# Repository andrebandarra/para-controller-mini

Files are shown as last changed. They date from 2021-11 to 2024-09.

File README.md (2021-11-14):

<h1 align="center">Para Controller Mini</h1>

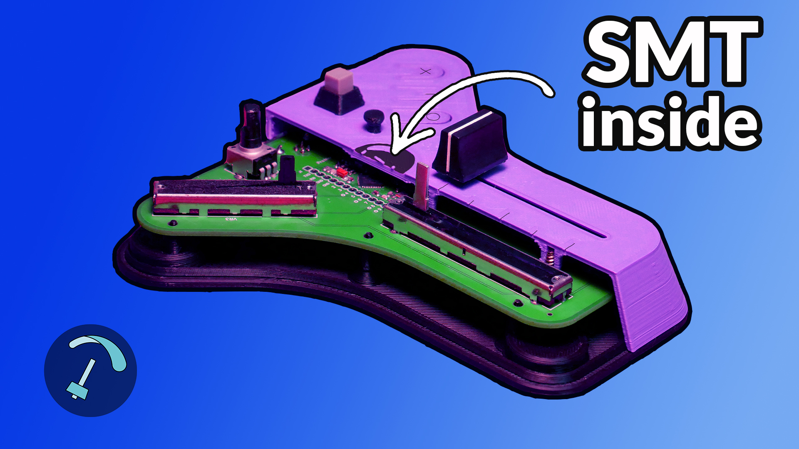
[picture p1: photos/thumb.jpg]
Table


https://www.youtube.com/watch?v=AOkSkCXVu8w --- https://andrebandarra.com/store/pcmini

## Description
I needed a small project to learn about SMT PCB design so this small game controller was the perfect project. I had to create my own Arduino Pro Micro with Surface mount components and was really happy that everything worked first time!

It is based on the Arduino Pro Micro by Sparkfun. I modified the original Eagle files to make a bigger board with space for all the SMT components and then ordered the half-done boards from JLCPCB. 

Then in-house I soldered the THT components like potentiometers, buttons, etc, and burned an arduino bootloader into the fresh 32U4 chips. Then thy can be programmed by the Arduino IDE.

Also created custom cases and 3D printed them. Finished plug and play units are available on my website.

## Features
* Plug and play game controller 
* Based on the Arduino Pro Micro (pins available for expansion and modification)
* Uses Joystick library, acts as a windows/mac default game controller
* 2 big linear potentiometers
* 1 small linear potentiometer
* 1 rotary potentiometer
* 1 latching switch
* 3 temporary switches
* 1 reset switch
* Usb interface

[andrebandarra.com](https://andrebandarra.com/) --- [Youtube](https://www.youtube.com/channel/UCzYf1cmKwDMSiII9SSp6IJw) --- [Patreon](https://www.patreon.com/bandarra)

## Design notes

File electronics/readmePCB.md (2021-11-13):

editable pcb files on EasyEDA

https://easyeda.com/Bandarra/test-import

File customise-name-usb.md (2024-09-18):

<h2>How to customise the USB name of your Arduino based Joystick</h2>
To customize the name of your Arduino-based joystick so that it's recognized with a custom name by Unity (or any operating system), you need to modify the USB descriptors on the Arduino. Since you are using an Arduino Micro, which is based on the ATmega32U4, it has native USB capabilities, and you can adjust the name via its firmware.

* In the Arduino IDE, go to the installation folder and find the boards.txt file:
C:\Program Files (x86)\Arduino\hardware\arduino\avr

* Open your text editor in Admin mode.

* Change the usb_product line to the name you want your device to show up as. It will look something like this:
micro.build.usb_product="ParaController Mini"

* Reflash the Arduino

Keep in mind that if the Arduino IDE or core libraries are updated, your changes might get overwritten, so you may want to back up these changes or use a custom boards file.

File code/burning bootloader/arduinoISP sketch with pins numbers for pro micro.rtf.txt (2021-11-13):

// ArduinoISP
// Copyright (c) 2008-2011 Randall Bohn
// If you require a license, see
// http://www.opensource.org/licenses/bsd-license.php
//
// This sketch turns the Arduino into a AVRISP using the following Arduino pins:
//
// Pin 10 is used to reset the target microcontroller.
//
// By default, the hardware SPI pins MISO, MOSI and SCK are used to communicate
// with the target. On all Arduinos, these pins can be found
// on the ICSP/SPI header:
//
//               MISO °. . 5V (!) Avoid this pin on Due, Zero...
//               SCK   . . MOSI
//                     . . GND
//
// On some Arduinos (Uno,...), pins MOSI, MISO and SCK are the same pins as
// digital pin 11, 12 and 13, respectively. That is why many tutorials instruct
// you to hook up the target to these pins. If you find this wiring more
// practical, have a define USE_OLD_STYLE_WIRING. This will work even when not
// using an Uno. (On an Uno this is not needed).
//
// Alternatively you can use any other digital pin by configuring
// software ('BitBanged') SPI and having appropriate defines for PIN_MOSI,
// PIN_MISO and PIN_SCK.
//
// IMPORTANT: When using an Arduino that is not 5V tolerant (Due, Zero, ...) as
// the programmer, make sure to not expose any of the programmer's pins to 5V.
// A simple way to accomplish this is to power the complete system (programmer
// and target) at 3V3.
//
// Put an LED (with resistor) on the following pins:
// 9: Heartbeat   - shows the programmer is running
// 8: Error       - Lights up if something goes wrong (use red if that makes sense)
// 7: Programming - In communication with the slave
//

#include "Arduino.h"
#undef SERIAL

#define PROG_FLICKER true

// Configure SPI clock (in Hz).
// E.g. for an ATtiny @ 128 kHz: the datasheet states that both the high and low
// SPI clock pulse must be > 2 CPU cycles, so take 3 cycles i.e. divide target
// f_cpu by 6:
//     #define SPI_CLOCK            (128000/6)
//
// A clock slow enough for an ATtiny85 @ 1 MHz, is a reasonable default:

#define SPI_CLOCK                 (1000000/6)

// Select hardware or software SPI, depending on SPI clock.
// Currently only for AVR, for other architectures (Due, Zero,...), hardware SPI
// is probably too fast anyway.

#if defined(ARDUINO_ARCH_AVR)

#if SPI_CLOCK > (F_CPU / 128)
#define USE_HARDWARE_SPI
#endif

#endif

// Configure which pins to use:

// The standard pin configuration.
#ifndef ARDUINO_HOODLOADER2

#define RESET     19 // Use pin 19 to reset the target rather than SS
#define LED_HB    9
#define LED_ERR   8
#define LED_PMODE 7

// Uncomment following line to use the old Uno style wiring
// (using pin 11, 12 and 13 instead of the SPI header) on Leonardo, Due...

// #define USE_OLD_STYLE_WIRING

#ifdef USE_OLD_STYLE_WIRING

#define PIN_MOSI        16
#define PIN_MISO        14
#define PIN_SCK                15

#endif

// HOODLOADER2 means running sketches on the ATmega16U2 serial converter chips
// on Uno or Mega boards. We must use pins that are broken out:
#else

#define RESET             4
#define LED_HB            7
#define LED_ERR           6
#define LED_PMODE         5

#endif

// By default, use hardware SPI pins:
#ifndef PIN_MOSI
#define PIN_MOSI         MOSI
#endif

#ifndef PIN_MISO
#define PIN_MISO         MISO
#endif

#ifndef PIN_SCK
#define PIN_SCK         SCK
#endif

// Force bitbanged SPI if not using the hardware SPI pins:
#if (PIN_MISO != MISO) ||  (PIN_MOSI != MOSI) || (PIN_SCK != SCK)
#undef USE_HARDWARE_SPI
#endif

// Configure the serial port to use.
//
// Prefer the USB virtual serial port (aka. native USB port), if the Arduino has one:
//   - it does not autoreset (except for the magic baud rate of 1200).
//   - it is more reliable because of USB handshaking.
//
// Leonardo and similar have an USB virtual serial port: 'Serial'.
// Due and Zero have an USB virtual serial port: 'SerialUSB'.
//
// On the Due and Zero, 'Serial' can be used too, provided you disable autoreset.
// To use 'Serial': #define SERIAL Serial

#ifdef SERIAL_PORT_USBVIRTUAL
#define SERIAL SERIAL_PORT_USBVIRTUAL
#else
#define SERIAL Serial
#endif

// Configure the baud rate:

#define BAUDRATE        19200
// #define BAUDRATE        115200
// #define BAUDRATE        1000000

#define HWVER 2
#define SWMAJ 1
#define SWMIN 18

// STK Definitions
#define STK_OK      0x10
#define STK_FAILED  0x11
#define STK_UNKNOWN 0x12
#define STK_INSYNC  0x14
#define STK_NOSYNC  0x15
#define CRC_EOP     0x20 //ok it is a space...

void pulse(int pin, int times);

#ifdef USE_HARDWARE_SPI
#include "SPI.h"
#else

#define SPI_MODE0 0x00

class SPISettings {
  public:
    // clock is in Hz
    SPISettings(uint32_t clock, uint8_t bitOrder, uint8_t dataMode) : clock(clock) {
      (void) bitOrder;
      (void) dataMode;
    };

  private:
    uint32_t clock;

    friend class BitBangedSPI;
};

class BitBangedSPI {
  public:
    void begin() {
      digitalWrite(PIN_SCK, LOW);
      digitalWrite(PIN_MOSI, LOW);
      pinMode(PIN_SCK, OUTPUT);
      pinMode(PIN_MOSI, OUTPUT);
      pinMode(PIN_MISO, INPUT);
    }

    void beginTransaction(SPISettings settings) {
      pulseWidth = (500000 + settings.clock - 1) / settings.clock;
      if (pulseWidth == 0)
        pulseWidth = 1;
    }

    void end() {}

    uint8_t transfer (uint8_t b) {
      for (unsigned int i = 0; i < 8; ++i) {
        digitalWrite(PIN_MOSI, (b & 0x80) ? HIGH : LOW);
        digitalWrite(PIN_SCK, HIGH);
        delayMicroseconds(pulseWidth);
        b = (b << 1) | digitalRead(PIN_MISO);
        digitalWrite(PIN_SCK, LOW); // slow pulse
        delayMicroseconds(pulseWidth);
      }
      return b;
    }

  private:
    unsigned long pulseWidth; // in microseconds
};

static BitBangedSPI SPI;

#endif

void setup() {
  SERIAL.begin(BAUDRATE);

  pinMode(LED_PMODE, OUTPUT);
  pulse(LED_PMODE, 2);
  pinMode(LED_ERR, OUTPUT);
  pulse(LED_ERR, 2);
  pinMode(LED_HB, OUTPUT);
  pulse(LED_HB, 2);

}

int error = 0;
int pmode = 0;
// address for reading and writing, set by 'U' command
unsigned int here;
uint8_t buff[256]; // global block storage

#define beget16(addr) (*addr * 256 + *(addr+1) )
typedef struct param {
  uint8_t devicecode;
  uint8_t revision;
  uint8_t progtype;
  uint8_t parmode;
  uint8_t polling;
  uint8_t selftimed;
  uint8_t lockbytes;
  uint8_t fusebytes;
  uint8_t flashpoll;
  uint16_t eeprompoll;
  uint16_t pagesize;
  uint16_t eepromsize;
  uint32_t flashsize;
}
parameter;

parameter param;

// this provides a heartbeat on pin 9, so you can tell the software is running.
uint8_t hbval = 128;
int8_t hbdelta = 8;
void heartbeat() {
  static unsigned long last_time = 0;
  unsigned long now = millis();
  if ((now - last_time) < 40)
    return;
  last_time = now;
  if (hbval > 192) hbdelta = -hbdelta;
  if (hbval < 32) hbdelta = -hbdelta;
  hbval += hbdelta;
  analogWrite(LED_HB, hbval);
}

static bool rst_active_high;

void reset_target(bool reset) {
  digitalWrite(RESET, ((reset && rst_active_high) || (!reset && !rst_active_high)) ? HIGH : LOW);
}

void loop(void) {
  // is pmode active?
  if (pmode) {
    digitalWrite(LED_PMODE, HIGH);
  } else {
    digitalWrite(LED_PMODE, LOW);
  }
  // is there an error?
  if (error) {
    digitalWrite(LED_ERR, HIGH);
  } else {
    digitalWrite(LED_ERR, LOW);
  }

  // light the heartbeat LED
  heartbeat();
  if (SERIAL.available()) {
    avrisp();
  }
}

uint8_t getch() {
  while (!SERIAL.available());
  return SERIAL.read();
}
void fill(int n) {
  for (int x = 0; x < n; x++) {
    buff[x] = getch();
  }
}

#define PTIME 30
void pulse(int pin, int times) {
  do {
    digitalWrite(pin, HIGH);
    delay(PTIME);
    digitalWrite(pin, LOW);
    delay(PTIME);
  } while (times--);
}

void prog_lamp(int state) {
  if (PROG_FLICKER) {
    digitalWrite(LED_PMODE, state);
  }
}

uint8_t spi_transaction(uint8_t a, uint8_t b, uint8_t c, uint8_t d) {
  SPI.transfer(a);
  SPI.transfer(b);
  SPI.transfer(c);
  return SPI.transfer(d);
}

void empty_reply() {
  if (CRC_EOP == getch()) {
    SERIAL.print((char)STK_INSYNC);
    SERIAL.print((char)STK_OK);
  } else {
    error++;
    SERIAL.print((char)STK_NOSYNC);
  }
}

void breply(uint8_t b) {
  if (CRC_EOP == getch()) {
    SERIAL.print((char)STK_INSYNC);
    SERIAL.print((char)b);
    SERIAL.print((char)STK_OK);
  } else {
    error++;
    SERIAL.print((char)STK_NOSYNC);
  }
}

void get_version(uint8_t c) {
  switch (c) {
    case 0x80:
      breply(HWVER);
      break;
    case 0x81:
      breply(SWMAJ);
      break;
    case 0x82:
      breply(SWMIN);
      break;
    case 0x93:
      breply('S'); // serial programmer
      break;
    default:
      breply(0);
  }
}

void set_parameters() {
  // call this after reading parameter packet into buff[]
  param.devicecode = buff[0];
  param.revision   = buff[1];
  param.progtype   = buff[2];
  param.parmode    = buff[3];
  param.polling    = buff[4];
  param.selftimed  = buff[5];
  param.lockbytes  = buff[6];
  param.fusebytes  = buff[7];
  param.flashpoll  = buff[8];
  // ignore buff[9] (= buff[8])
  // following are 16 bits (big endian)
  param.eeprompoll = beget16(&buff[10]);
  param.pagesize   = beget16(&buff[12]);
  param.eepromsize = beget16(&buff[14]);

  // 32 bits flashsize (big endian)
  param.flashsize = buff[16] * 0x01000000
                    + buff[17] * 0x00010000
                    + buff[18] * 0x00000100
                    + buff[19];

  // AVR devices have active low reset, AT89Sx are active high
  rst_active_high = (param.devicecode >= 0xe0);
}

void start_pmode() {

  // Reset target before driving PIN_SCK or PIN_MOSI

  // SPI.begin() will configure SS as output, so SPI master mode is selected.
  // We have defined RESET as pin 10, which for many Arduinos is not the SS pin.
  // So we have to configure RESET as output here,
  // (reset_target() first sets the correct level)
  reset_target(true);
  pinMode(RESET, OUTPUT);
  SPI.begin();
  SPI.beginTransaction(SPISettings(SPI_CLOCK, MSBFIRST, SPI_MODE0));

  // See AVR datasheets, chapter "SERIAL_PRG Programming Algorithm":

  // Pulse RESET after PIN_SCK is low:
  digitalWrite(PIN_SCK, LOW);
  delay(20); // discharge PIN_SCK, value arbitrarily chosen
  reset_target(false);
  // Pulse must be minimum 2 target CPU clock cycles so 100 usec is ok for CPU
  // speeds above 20 KHz
  delayMicroseconds(100);
  reset_target(true);

  // Send the enable programming command:
  delay(50); // datasheet: must be > 20 msec
  spi_transaction(0xAC, 0x53, 0x00, 0x00);
  pmode = 1;
}

void end_pmode() {
  SPI.end();
  // We're about to take the target out of reset so configure SPI pins as input
  pinMode(PIN_MOSI, INPUT);
  pinMode(PIN_SCK, INPUT);
  reset_target(false);
  pinMode(RESET, INPUT);
  pmode = 0;
}

void universal() {
  uint8_t ch;

  fill(4);
  ch = spi_transaction(buff[0], buff[1], buff[2], buff[3]);
  breply(ch);
}

void flash(uint8_t hilo, unsigned int addr, uint8_t data) {
  spi_transaction(0x40 + 8 * hilo,
                  addr >> 8 & 0xFF,
                  addr & 0xFF,
                  data);
}
void commit(unsigned int addr) {
  if (PROG_FLICKER) {
    prog_lamp(LOW);
  }
  spi_transaction(0x4C, (addr >> 8) & 0xFF, addr & 0xFF, 0);
  if (PROG_FLICKER) {
    delay(PTIME);
    prog_lamp(HIGH);
  }
}

unsigned int current_page() {
  if (param.pagesize == 32) {
    return here & 0xFFFFFFF0;
  }
  if (param.pagesize == 64) {
    return here & 0xFFFFFFE0;
  }
  if (param.pagesize == 128) {
    return here & 0xFFFFFFC0;
  }
  if (param.pagesize == 256) {
    return here & 0xFFFFFF80;
  }
  return here;
}

void write_flash(int length) {
  fill(length);
  if (CRC_EOP == getch()) {
    SERIAL.print((char) STK_INSYNC);
    SERIAL.print((char) write_flash_pages(length));
  } else {
    error++;
    SERIAL.print((char) STK_NOSYNC);
  }
}

uint8_t write_flash_pages(int length) {
  int x = 0;
  unsigned int page = current_page();
  while (x < length) {
    if (page != current_page()) {
      commit(page);
      page = current_page();
    }
    flash(LOW, here, buff[x++]);
    flash(HIGH, here, buff[x++]);
    here++;
  }

  commit(page);

  return STK_OK;
}

#define EECHUNK (32)
uint8_t write_eeprom(unsigned int length) {
  // here is a word address, get the byte address
  unsigned int start = here * 2;
  unsigned int remaining = length;
  if (length > param.eepromsize) {
    error++;
    return STK_FAILED;
  }
  while (remaining > EECHUNK) {
    write_eeprom_chunk(start, EECHUNK);
    start += EECHUNK;
    remaining -= EECHUNK;
  }
  write_eeprom_chunk(start, remaining);
  return STK_OK;
}
// write (length) bytes, (start) is a byte address
uint8_t write_eeprom_chunk(unsigned int start, unsigned int length) {
  // this writes byte-by-byte, page writing may be faster (4 bytes at a time)
  fill(length);
  prog_lamp(LOW);
  for (unsigned int x = 0; x < length; x++) {
    unsigned int addr = start + x;
    spi_transaction(0xC0, (addr >> 8) & 0xFF, addr & 0xFF, buff[x]);
    delay(45);
  }
  prog_lamp(HIGH);
  return STK_OK;
}

void program_page() {
  char result = (char) STK_FAILED;
  unsigned int length = 256 * getch();
  length += getch();
  char memtype = getch();
  // flash memory @here, (length) bytes
  if (memtype == 'F') {
    write_flash(length);
    return;
  }
  if (memtype == 'E') {
    result = (char)write_eeprom(length);
    if (CRC_EOP == getch()) {
      SERIAL.print((char) STK_INSYNC);
      SERIAL.print(result);
    } else {
      error++;
      SERIAL.print((char) STK_NOSYNC);
    }
    return;
  }
  SERIAL.print((char)STK_FAILED);
  return;
}

uint8_t flash_read(uint8_t hilo, unsigned int addr) {
  return spi_transaction(0x20 + hilo * 8,
                         (addr >> 8) & 0xFF,
                         addr & 0xFF,
                         0);
}

char flash_read_page(int length) {
  for (int x = 0; x < length; x += 2) {
    uint8_t low = flash_read(LOW, here);
    SERIAL.print((char) low);
    uint8_t high = flash_read(HIGH, here);
    SERIAL.print((char) high);
    here++;
  }
  return STK_OK;
}

char eeprom_read_page(int length) {
  // here again we have a word address
  int start = here * 2;
  for (int x = 0; x < length; x++) {
    int addr = start + x;
    uint8_t ee = spi_transaction(0xA0, (addr >> 8) & 0xFF, addr & 0xFF, 0xFF);
    SERIAL.print((char) ee);
  }
  return STK_OK;
}

void read_page() {
  char result = (char)STK_FAILED;
  int length = 256 * getch();
  length += getch();
  char memtype = getch();
  if (CRC_EOP != getch()) {
    error++;
    SERIAL.print((char) STK_NOSYNC);
    return;
  }
  SERIAL.print((char) STK_INSYNC);
  if (memtype == 'F') result = flash_read_page(length);
  if (memtype == 'E') result = eeprom_read_page(length);
  SERIAL.print(result);
}

void read_signature() {
  if (CRC_EOP != getch()) {
    error++;
    SERIAL.print((char) STK_NOSYNC);
    return;
  }
  SERIAL.print((char) STK_INSYNC);
  uint8_t high = spi_transaction(0x30, 0x00, 0x00, 0x00);
  SERIAL.print((char) high);
  uint8_t middle = spi_transaction(0x30, 0x00, 0x01, 0x00);
  SERIAL.print((char) middle);
  uint8_t low = spi_transaction(0x30, 0x00, 0x02, 0x00);
  SERIAL.print((char) low);
  SERIAL.print((char) STK_OK);
}
//////////////////////////////////////////
//////////////////////////////////////////

////////////////////////////////////
////////////////////////////////////
void avrisp() {
  uint8_t ch = getch();
  switch (ch) {
    case '0': // signon
      error = 0;
      empty_reply();
      break;
    case '1':
      if (getch() == CRC_EOP) {
        SERIAL.print((char) STK_INSYNC);
        SERIAL.print("AVR ISP");
        SERIAL.print((char) STK_OK);
      }
      else {
        error++;
        SERIAL.print((char) STK_NOSYNC);
      }
      break;
    case 'A':
      get_version(getch());
      break;
    case 'B':
      fill(20);
      set_parameters();
      empty_reply();
      break;
    case 'E': // extended parameters - ignore for now
      fill(5);
      empty_reply();
      break;
    case 'P':
      if (!pmode)
        start_pmode();
      empty_reply();
      break;
    case 'U': // set address (word)
      here = getch();
      here += 256 * getch();
      empty_reply();
      break;

    case 0x60: //STK_PROG_FLASH
      getch(); // low addr
      getch(); // high addr
      empty_reply();
      break;
    case 0x61: //STK_PROG_DATA
      getch(); // data
      empty_reply();
      break;

    case 0x64: //STK_PROG_PAGE
      program_page();
      break;

    case 0x74: //STK_READ_PAGE 't'
      read_page();
      break;

    case 'V': //0x56
      universal();
      break;
    case 'Q': //0x51
      error = 0;
      end_pmode();
      empty_reply();
      break;

    case 0x75: //STK_READ_SIGN 'u'
      read_signature();
      break;

    // expecting a command, not CRC_EOP
    // this is how we can get back in sync
    case CRC_EOP:
      error++;
      SERIAL.print((char) STK_NOSYNC);
      break;

    // anything else we will return STK_UNKNOWN
    default:
      error++;
      if (CRC_EOP == getch())
        SERIAL.print((char)STK_UNKNOWN);
      else
        SERIAL.print((char)STK_NOSYNC);
  }
}

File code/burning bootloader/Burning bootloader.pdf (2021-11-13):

Burning arduino bootloader to 32U4 chip using another arduino pro micro

--- Skip Step 0 and Step 1 if already have master arduino and cable ready ---

Step 0
Connect master arduino pro micro to computer via usb
Step 1
Using Arduino IDE upload modified ArduinoISP sketch (in this folder) to the master arduino pro micro
(modification is Pin reset >19, PIN_MOSI > 16, PIN_MISO > 14, PIN_SCK > 15)
Step 2
Connect Master pro micro to Slave pro micro via ISP pins + GND&VCC + pin19 (master to Reset (slave)
- When using Master/slave custom cable, make sure VCC and GND match on both boards
Step 3
Select Tools > Programmer: > Arduino as ISP (ATmega32U4)
Step 4
Click Tools > Burn Bootloader
Step 5
Takes about 5-10 seconds, when done all 3 LEDs on slave arduino micro come on. Unplug usb cable and all ready to go

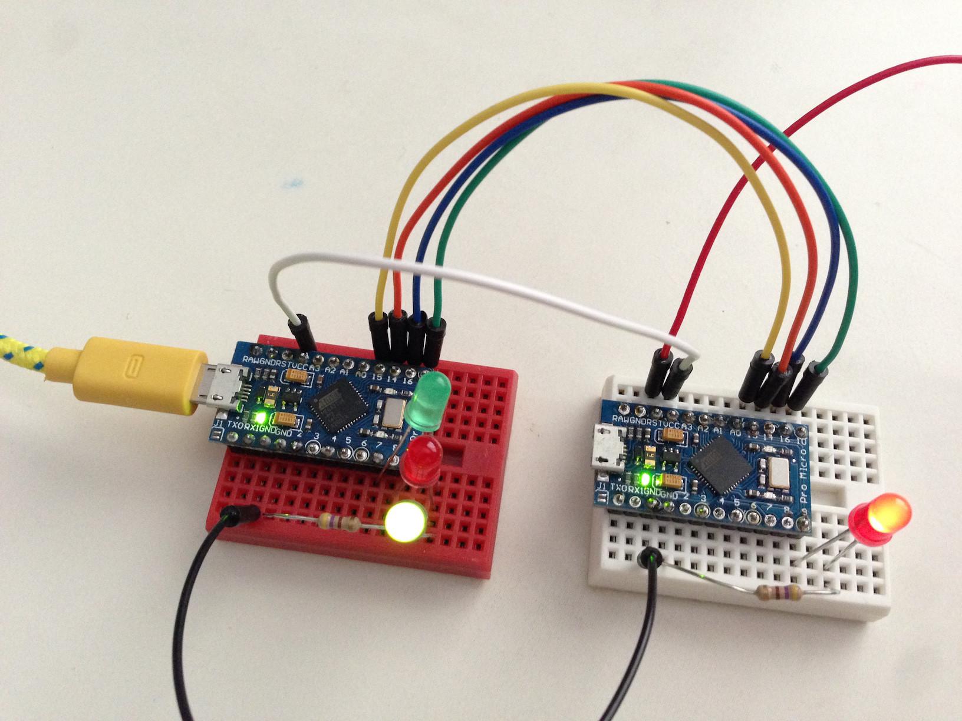
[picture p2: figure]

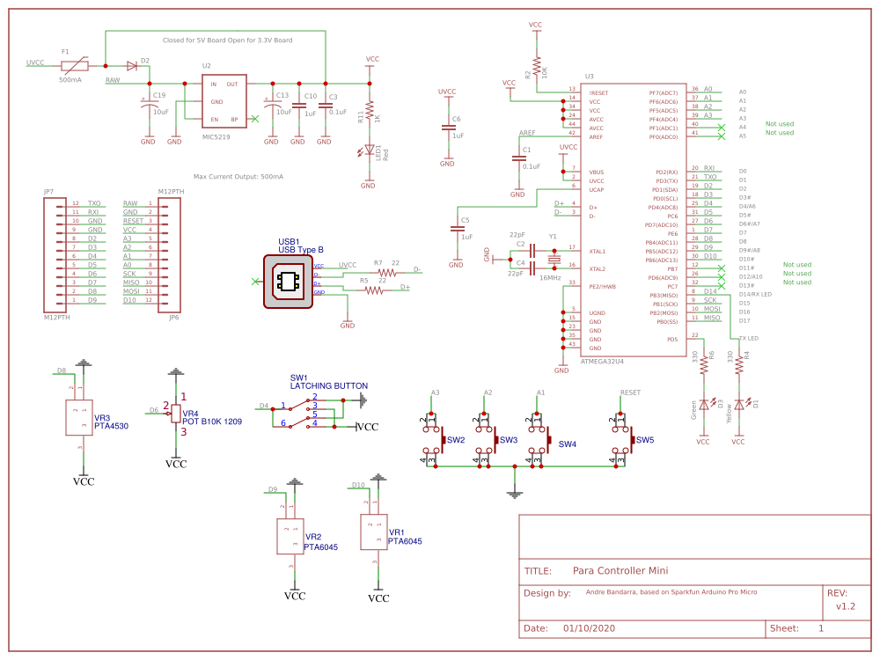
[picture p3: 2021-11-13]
electronics/schematics and BOM/pcmini schematic.png

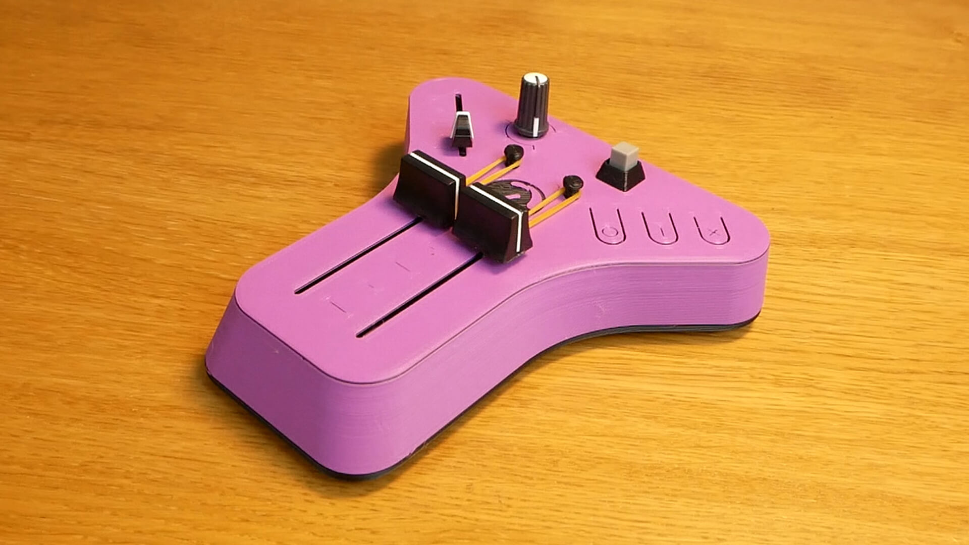
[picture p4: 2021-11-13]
photos/para controller mini.00_07_25_46.Still001.jpg

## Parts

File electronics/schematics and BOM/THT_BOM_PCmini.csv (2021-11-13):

THD components | #
6045 B10K | 2
4530 B10K | 1
Circ B10K | 1
Latch switch & cap | 1
temp buttons 4.3mm | 4
Big slider caps | 2
Small slider caps | 1
Circ cap | 1
Square cap | 1
usb socket | 1
3D Printing
top | 1
bot | 1
square riser | 1
rubber pegs | 1
Other
Rubber feet | 4
usb cable A2B | 1
Rubber bands | 6
screws | 4

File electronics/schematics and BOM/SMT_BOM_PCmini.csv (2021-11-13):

ID | Name | Designator | Footprint | Quantity
1 | 22pF | C2,C4 | 0603-CAP | 2
2 | 0.1uF | C1,C3 | 0603-CAP | 2
3 | 1uF | C5,C6,C10 | 0603-CAP | 3
4 | 10uF | C13,C19 | EIA3216 | 2
5 | Yellow | D1 | LED-0603 | 1
6 | DIODESOD | D2 | SOD-323 | 1
7 | Green | D3 | LED-0603 | 1
8 | 500mA | F1 | PTC-1206 | 1
9 | FRAME-LETTER | FRAME1 | CREATIVE_COMMONS | 1
10 | M12PTH | JP6,JP7 | 1X12 | 2
11 | Red | LED1 | LED-0603 | 1
12 | 10K | R2 | 0603-RES | 1
13 | 22 | R5,R7 | 0603-RES | 2
14 | 330 | R4,R6 | 0603-RES | 2
15 | 1K | R11 | 0603-RES | 1
16 | LATCHING BUTTON | SW1 | LATCHING BUTTON 8X8 6PIN BANDARRA | 1
17 | 6x6 PushButton | SW2,SW3,SW4,SW5 | KEY-6.0*6.0-2 | 4
18 | MIC5219 | U2 | SOT23-5 | 1
19 | ATMEGA32U4 | U3 | QFN-44-NOPAD_1:1-OUTFAKES | 1
20 | USB Type B | USB1 | USB-M-49 | 1
21 | PTA6045 | VR1,VR2 | PTA6043 | 2
22 | PTA4530 | VR3 | PTA4530 B10K BANDARRA | 1
23 | POT B10K 1209 | VR4 | POT B10K 1209 | 1
24 | 16MHz | Y1 | CRYSTAL-SMD-5X3 | 1

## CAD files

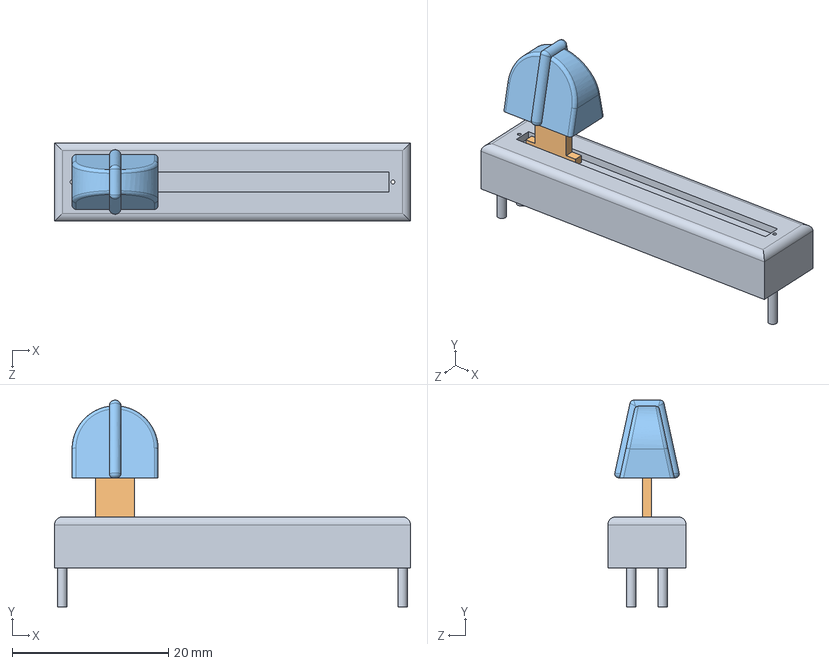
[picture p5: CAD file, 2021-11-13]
cad/assemblies/45slider.SLDASM
45.5 x 26.4 x 10.0 mm
45 slider body
45 slider peg
45 slider cap

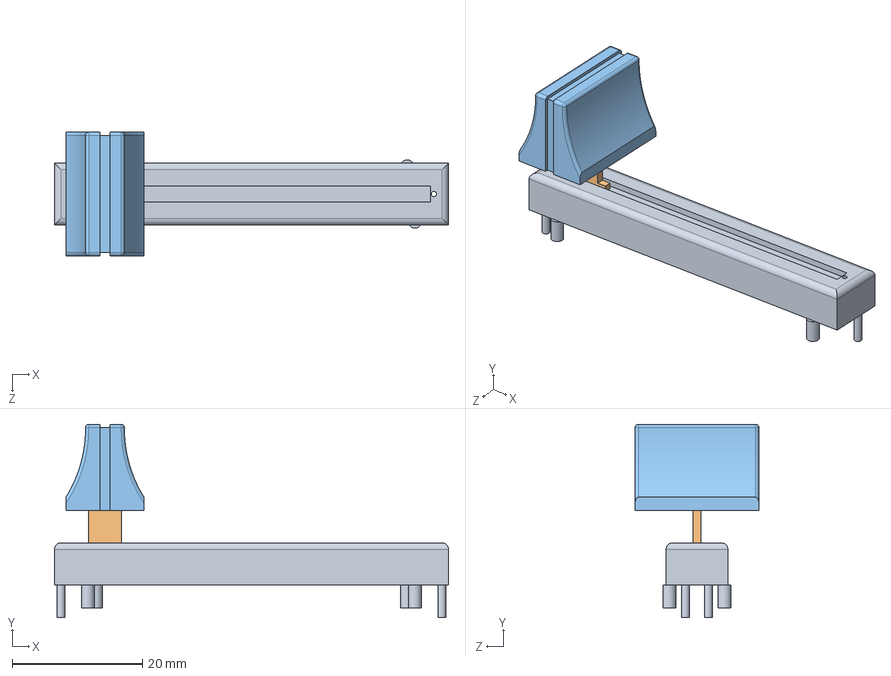
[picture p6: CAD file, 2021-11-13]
cad/assemblies/60slider.SLDASM
60.5 x 29.7 x 19.0 mm
60 slider body
60 slider peg
60 slider cap

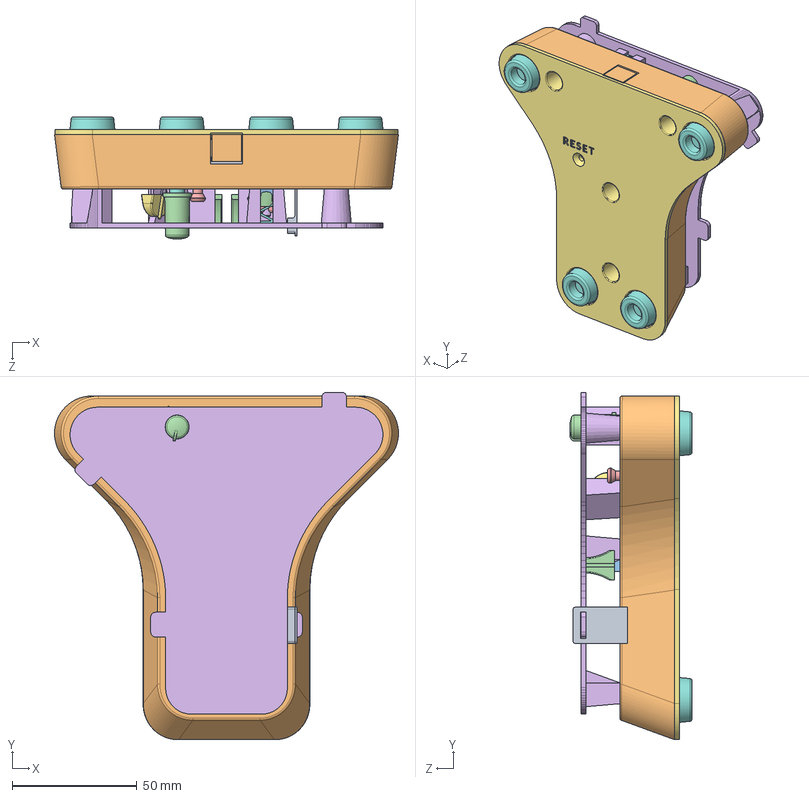
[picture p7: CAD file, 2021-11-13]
cad/assemblies/Mini Para Joy.SLDASM
138.1 x 139.5 x 49.1 mm
pcb ordered
60 slider body x 2
60 slider peg x 2
60 slider cap x 2
45 slider body
45 slider peg
45 slider cap
270potB10K half shaft
888button
usb B socket
H8temp button x 4
90deghalfaxispotcat6mm
round cap
bot case1
rubber foot x 4
3mm plastic screw x 4
top case
round button riser
rubber band peg x 2

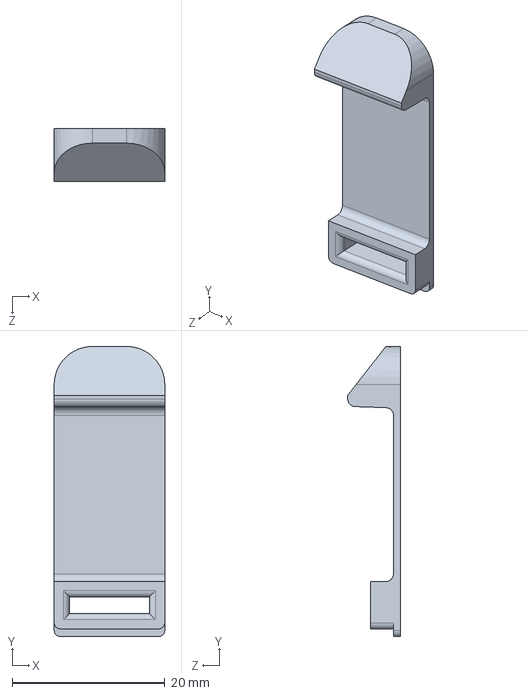
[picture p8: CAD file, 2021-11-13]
cad/parts/jigs/pcb clip.SLDPRT
14.5 x 38.0 x 6.90 mm

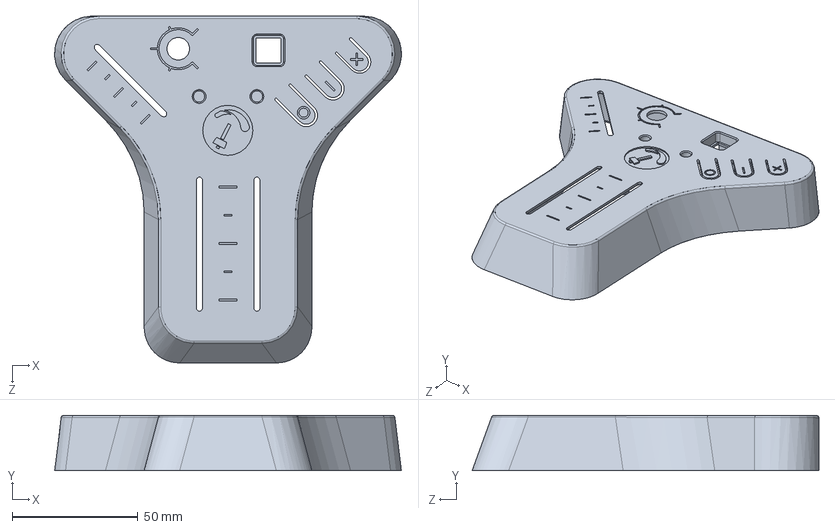
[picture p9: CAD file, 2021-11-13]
cad/parts/top case.SLDPRT
138.1 x 22.0 x 138.0 mm

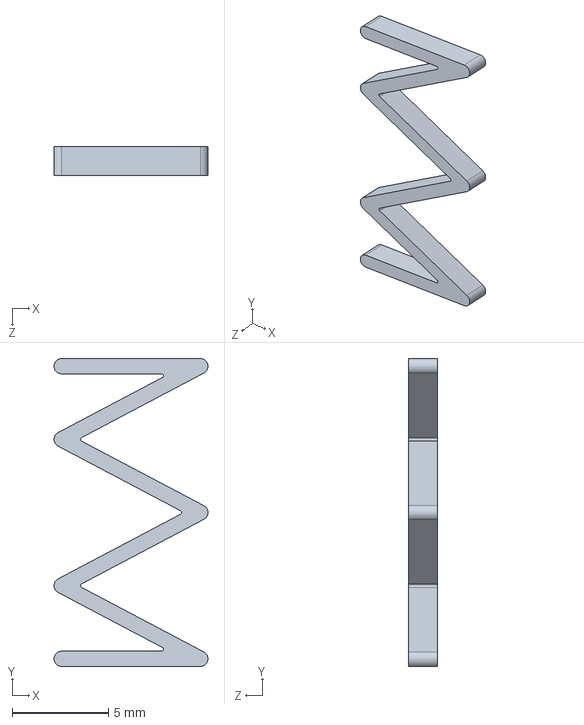
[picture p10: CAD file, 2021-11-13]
cad/parts/jigs/spring small.SLDPRT
8.00 x 16.0 x 1.50 mm

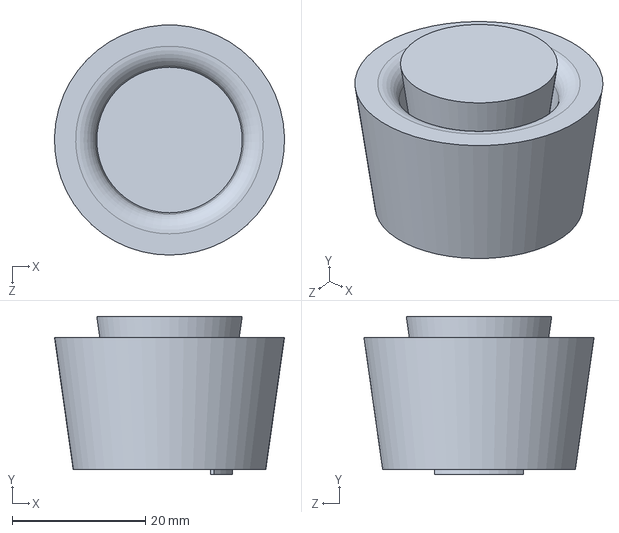
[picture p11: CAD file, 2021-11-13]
cad/parts/jigs/cone.SLDPRT
34.6 x 23.8 x 34.6 mm

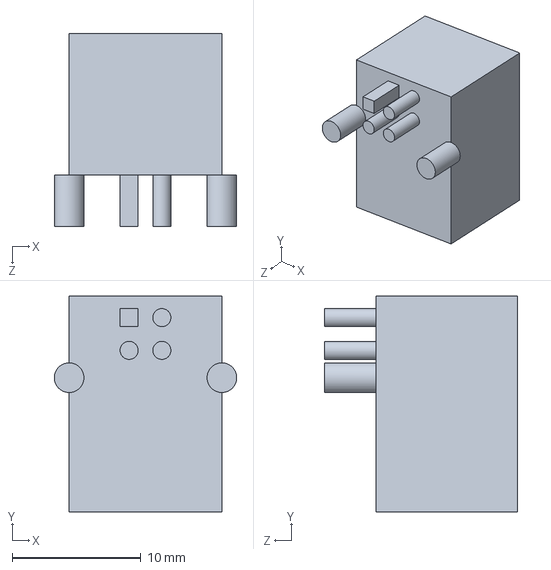
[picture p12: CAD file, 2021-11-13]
cad/parts/usb B socket.SLDPRT
14.1 x 16.7 x 15.0 mm

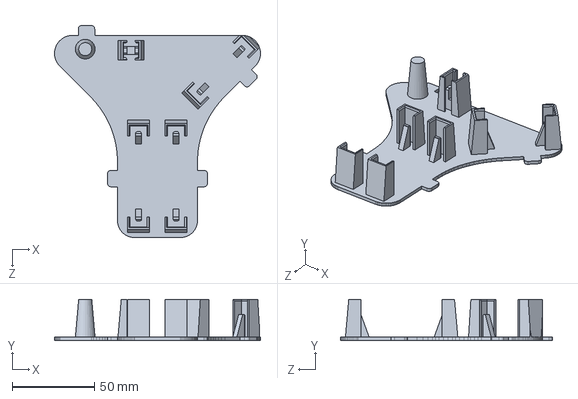
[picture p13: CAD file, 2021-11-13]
cad/parts/jigs/solder jig.SLDPRT
125.6 x 25.0 x 129.2 mm

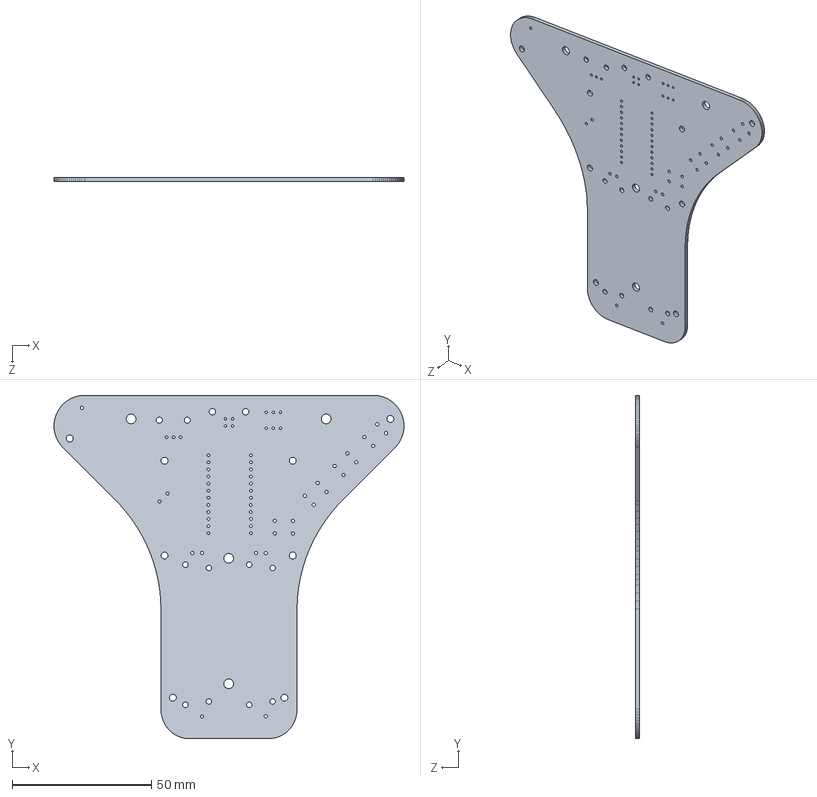
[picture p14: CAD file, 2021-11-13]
cad/parts/pcb ordered.SLDPRT
125.6 x 123.2 x 1.60 mm

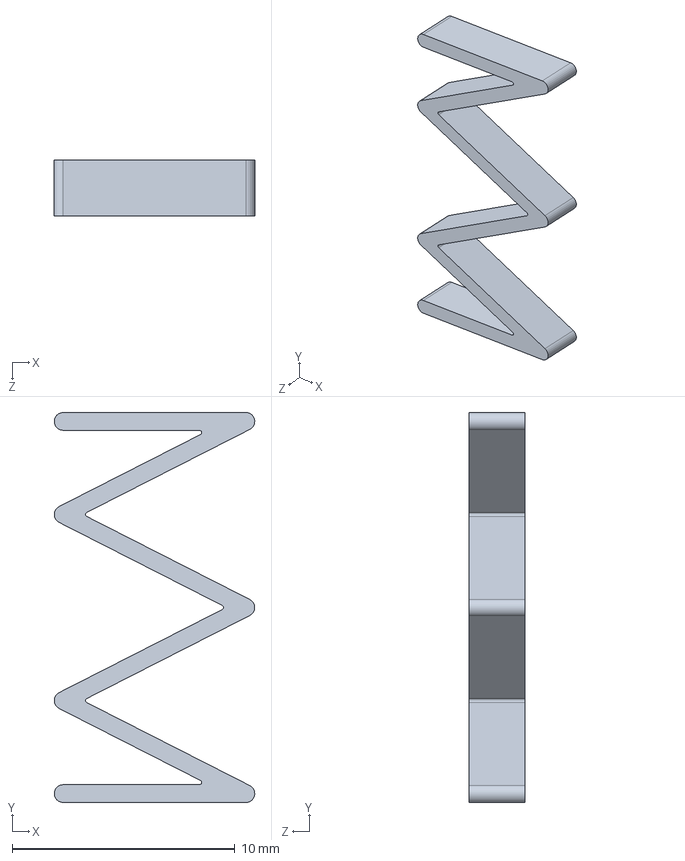
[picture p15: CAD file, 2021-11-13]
cad/parts/jigs/spring large.SLDPRT
9.00 x 17.5 x 2.50 mm

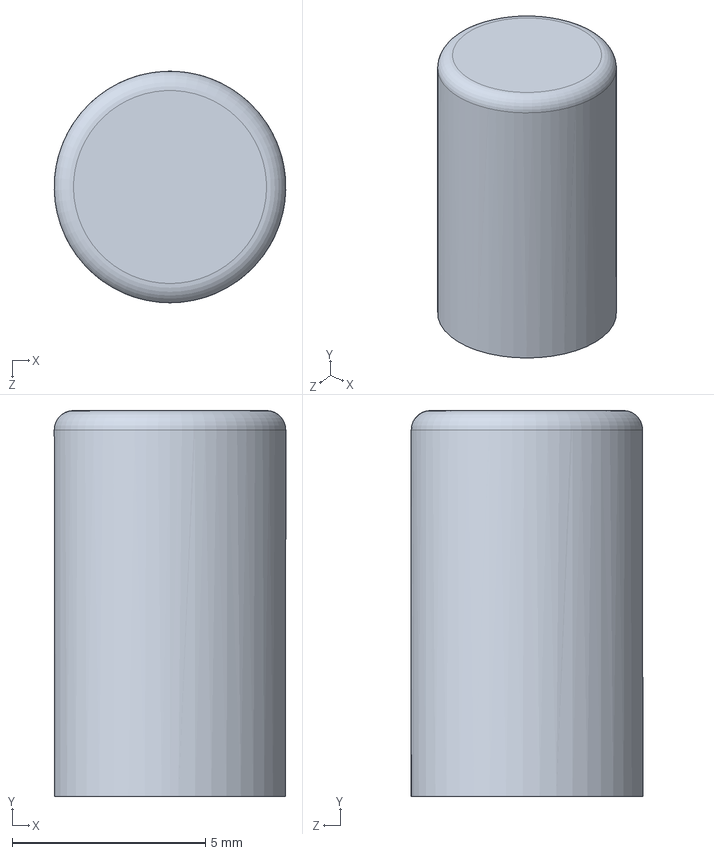
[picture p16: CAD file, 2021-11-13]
cad/parts/round cap.SLDPRT
6.00 x 10.0 x 6.00 mm

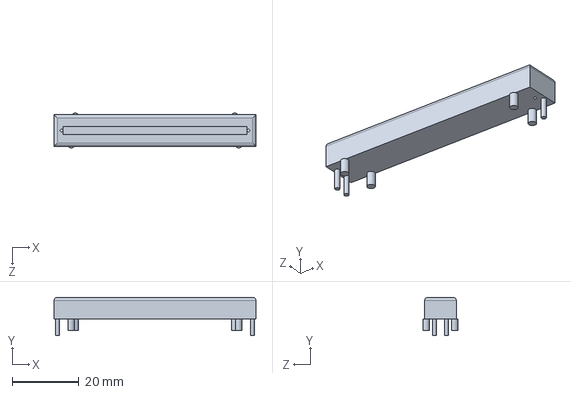
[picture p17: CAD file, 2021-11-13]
cad/parts/60 slider body.SLDPRT
60.5 x 11.5 x 10.5 mm

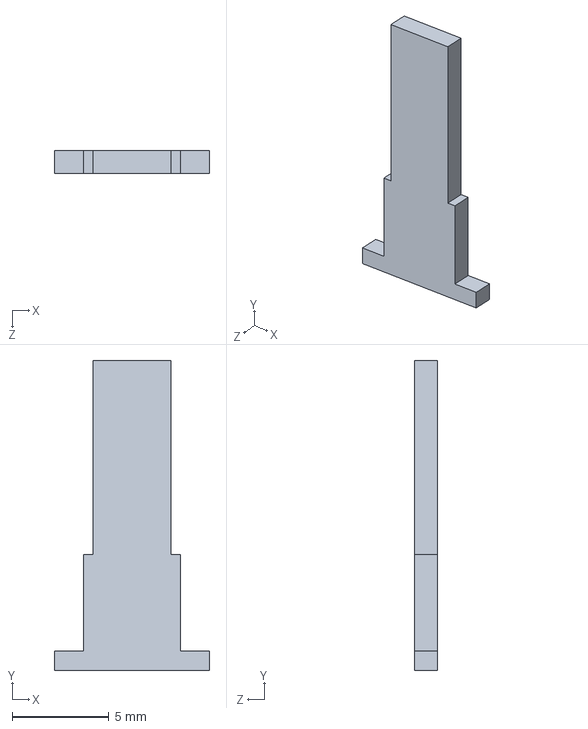
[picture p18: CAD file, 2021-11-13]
cad/parts/60 slider peg.SLDPRT
8.00 x 16.0 x 1.20 mm

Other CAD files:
cad/parts/top case2.SLDPRT
cad/parts/square cap.SLDPRT
cad/parts/H8temp button.SLDPRT
cad/parts/Pro_Micro.SLDPRT
cad/parts/270potA10K .SLDPRT
cad/parts/270potB10K half shaft.SLDPRT
cad/parts/3mm plastic screw.SLDPRT
cad/parts/45 slider body.SLDPRT
cad/parts/45 slider cap.SLDPRT
cad/parts/45 slider peg.SLDPRT
cad/parts/60 slider cap.SLDPRT
cad/parts/888button.SLDPRT
cad/parts/90deghalfaxispotcat6mm.SLDPRT
cad/parts/bot case.SLDPRT
cad/parts/bot case1.SLDPRT
cad/parts/button plug.SLDPRT
cad/parts/foot rubber.SLDPRT
cad/parts/pcb hole check.SLDPRT
cad/parts/round button riser.SLDPRT
cad/parts/rubber band peg.SLDPRT
cad/parts/rubber foot.SLDPRT
cad/parts/square button riser.SLDPRT

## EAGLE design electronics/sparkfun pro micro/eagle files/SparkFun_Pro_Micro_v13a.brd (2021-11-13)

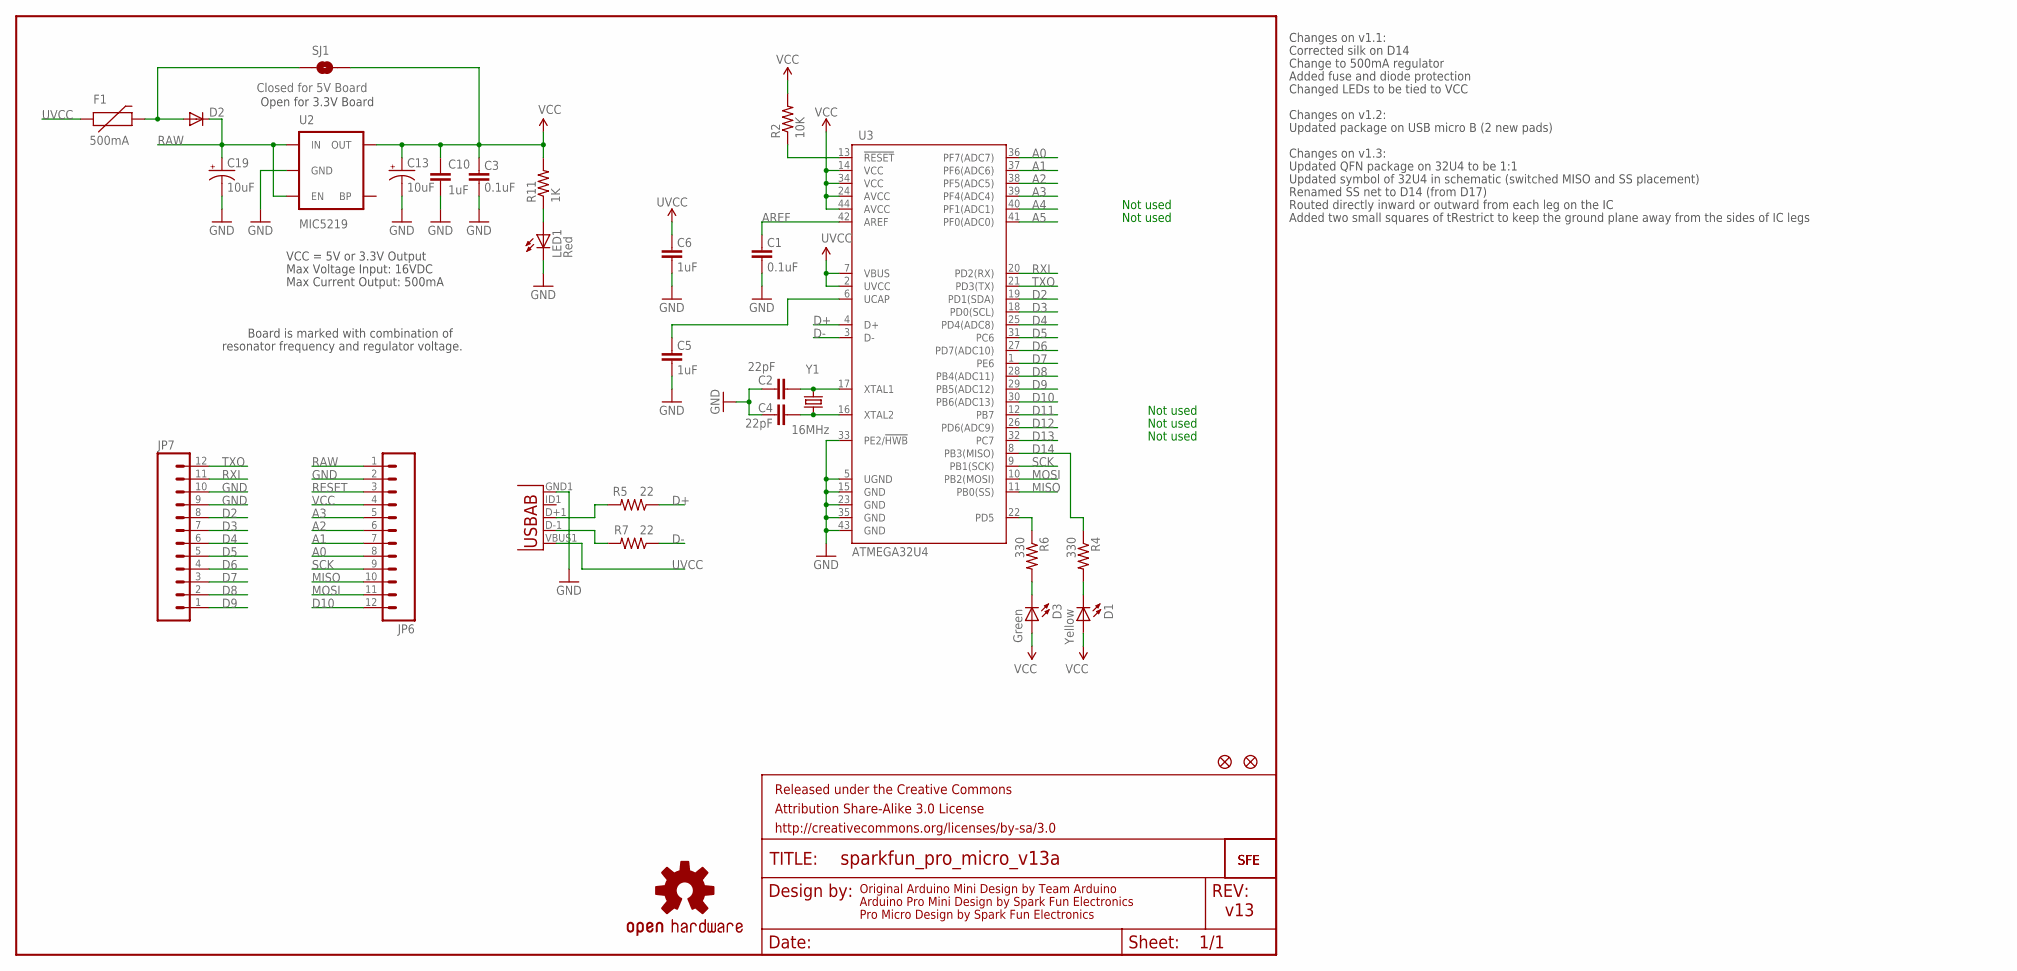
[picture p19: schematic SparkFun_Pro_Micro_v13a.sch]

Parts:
C1, C3: 0.1uF; 0603-CAP
C2, C4: 22pF; 0603-CAP
C5, C6, C10: 1uF; 0603-CAP
C13, C19: 10uF; EIA3216
D1: Yellow; LED-0603
D2: DIODESOD; SOD-323
D3: Green; LED-0603
F1: 500mA; PTC-1206
FRAME1: FRAME-LETTER; CREATIVE_COMMONS
JP1, JP2: FIDUCIALUFIDUCIAL; MICRO-FIDUCIAL
JP6, JP7: M12PTH; 1X12
LED1: Red; LED-0603
R2: 10K; 0603-RES
R4, R6: 330; 0603-RES
R5, R7: 22; 0603-RES
R11: 1K; 0603-RES
SJ1: Closed for 5V Board; SJ_2S
U2: MIC5219; SOT23-5
U3: ATMEGA32U4; QFN-44-NOPAD_1:1-OUTFAKES
U$1: LOGO-SFESK; SFE-LOGO-FLAME
U$3: OSHW-LOGOS; OSHW-LOGO-S
U$11: LOGO-SFENEW; SFE-NEW-WEBLOGO
X1: USB-ABIN&OUT; USB-AB-MICRO-SMD-V03-IN&OUT
Y1: 16MHz; CRYSTAL-SMD-5X3

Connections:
A0: JP6.8, U3.36 (PF7(ADC7))
A1: JP6.7, U3.37 (PF6(ADC6))
A2: JP6.6, U3.38 (PF5(ADC5))
A3: JP6.5, U3.39 (PF4(ADC4))
A4: U3.40 (PF1(ADC1))
A5: U3.41 (PF0(ADC0))
AREF: C1.2, U3.42 (AREF)
D2: JP7.8, U3.19 (PD1(SDA))
D3: JP7.7, U3.18 (PD0(SCL))
D4: JP7.6, U3.25 (PD4(ADC8))
D5: JP7.5, U3.31 (PC6)
D6: JP7.4, U3.27 (PD7(ADC10))
D7: JP7.3, U3.1 (PE6)
D8: JP7.2, U3.28 (PB4(ADC11))
D9: JP7.1, U3.29 (PB5(ADC12))
D10: JP6.12, U3.30 (PB6(ADC13))
D11: U3.12 (PB7)
D12: U3.26 (PD6(ADC9))
D13: U3.32 (PC7)
D14: R4.1, U3.8 (PB3(MISO))
D+: R5.1, U3.4 (D+)
D-: R7.1, U3.3 (D-)
GND: C1.1, C2.2, C3.1, C4.2, C5.1, C6.1, C10.2, C13.C (-), C19.C (-), JP6.2, JP7.9, JP7.10, LED1.C, U2.2 (GND), U3.5 (UGND), U3.15 (GND), U3.23 (GND), U3.33 (PE2/!HWB), U3.35 (GND), U3.43 (GND), X1.GND1 (GND)
MISO: JP6.10, U3.11 (PB0(SS))
MOSI: JP6.11, U3.10 (PB2(MOSI))
unnamed: C4.1, U3.16 (XTAL2), Y1.1
unnamed: C2.1, U3.17 (XTAL1), Y1.3 (2)
unnamed: D2.2 (A), F1.2, SJ1.1
unnamed: C5.2, U3.6 (UCAP)
unnamed: D1.C, R4.2
unnamed: R7.2, X1.D-1 (D-)
unnamed: D3.C, R6.2
unnamed: R5.2, X1.D+1 (D+)
unnamed: LED1.A, R11.1
RAW: C19.A (+), D2.1 (C), JP6.1, U2.1 (IN), U2.3 (EN)
RESET: JP6.3, R2.1, U3.13 (!RESET)
RXI: JP7.11, U3.20 (PD2(RX))
SCK: JP6.9, U3.9 (PB1(SCK))
TXLED: R6.1, U3.22 (PD5)
TXO: JP7.12, U3.21 (PD3(TX))
UVCC: C6.2, F1.1, U3.2 (UVCC), U3.7 (VBUS), X1.VBUS1 (VBUS)
VCC: C3.2, C10.1, C13.A (+), D1.A, D3.A, JP6.4, R2.2, R11.2, SJ1.2, U2.5 (OUT), U3.14 (VCC), U3.24 (AVCC), U3.34 (VCC), U3.44 (AVCC)

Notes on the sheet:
Original Arduino Mini Design by Team Arduino
Arduino Pro Mini Design by Spark Fun Electronics
Max Voltage Input: 16VDC
Max Current Output: 500mA
Board is marked with combination of
resonator frequency and regulator voltage.
VCC = 5V or 3.3V Output
Not used
Pro Micro Design by Spark Fun Electronics
Changes on v1.1:
Corrected silk on D14
Change to 500mA regulator
Open for 3.3V Board
Added fuse and diode protection
Changed LEDs to be tied to VCC
Changes on v1.2:
Updated package on USB micro B (2 new pads)
Changes on v1.3:
Updated QFN package on 32U4 to be 1:1
Updated symbol of 32U4 in schematic (switched MISO and SS placement)
Renamed SS net to D14 (from D17)
Routed directly inward or outward from each leg on the IC
Added two small squares of tRestrict to keep the ground plane away from the sides of IC legs
v13

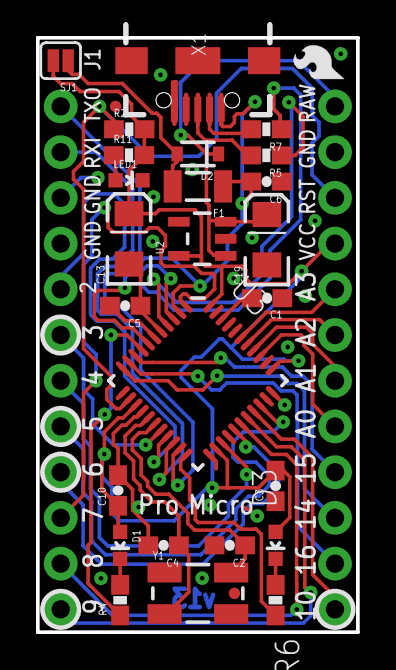
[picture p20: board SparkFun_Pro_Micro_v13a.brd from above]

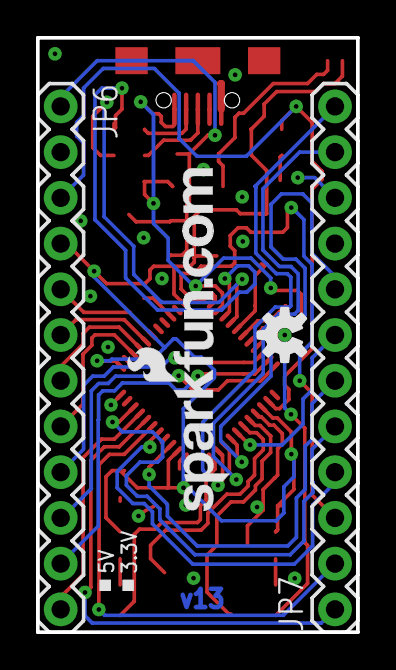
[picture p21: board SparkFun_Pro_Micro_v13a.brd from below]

Board: 2 copper layers, 17.8 x 33.0 mm, 33 parts (4 on the bottom side), 37 nets.

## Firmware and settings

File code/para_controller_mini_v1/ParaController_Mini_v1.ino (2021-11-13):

/*ParaController Mini v1

By Andre Bandarra https://andrebandarra.com/

Hardware
Uses the Para Controller Mini V1 PCB based on the Arduino Pro Micro

Software
Uses Joystick library V1  https://github.com/MHeironimus/ArduinoJoystickLibrary/tree/version-1.0

Setup
- Defines switches and potentiometer input pins
- Starts Joystick entity
Loop
- Checks button states and updates
- Checks pot values and updates

*/

#include <Joystick.h>

#define MAX_SWITCHES 4                            //number of switches
byte switch_pin[MAX_SWITCHES] = {A6, A1, A2, A3}; // digital input pins for switches
#define DEBOUNCE_TIME 5                           // ms delay before the push button changes state
#define MAX_ANALOG 4                              //number of analog potentiometers
byte analog_pin[MAX_ANALOG] = {A10, A9, A8, A7};  //array of input pins for potentiometers
int readvalues[8];                                //array of input read values

byte reading, switch_state[MAX_SWITCHES], switch_state_old[MAX_SWITCHES];
int analog_value[MAX_ANALOG];
unsigned long debounce_time[MAX_SWITCHES];


void setup() {

// Serial.begin(9600);    use serial for debugging

  for (int i = 0; i < MAX_SWITCHES; i++){
      pinMode(switch_pin[i], INPUT_PULLUP);
      }

  Joystick.begin();                       
}

void loop() {


  for (byte i=0; i<MAX_SWITCHES; i++) {                                                         // read the switches
    reading = !digitalRead(switch_pin[i]);
    if (reading == switch_state[i]) debounce_time[i] = millis() + (unsigned long)DEBOUNCE_TIME;
    else if (millis() > debounce_time[i]) switch_state[i] = reading;
    if (switch_state[i] != switch_state_old[i]) {                                               // debounced button has changed state
      // this code is executed once after change of state
      digitalWrite(13,switch_state[i]);
      if (switch_state[i]) Joystick.pressButton(i); else Joystick.releaseButton(i);
        switch_state_old[i] = switch_state[i];                                                  // store new state such that the above gets done only once
    }
  } //END read switches


  for (byte i=0; i<MAX_ANALOG; i++) {                                                           // read analog inputs in sequence
    analog_value[i] = analogRead(analog_pin[i]);

    switch(i) {
      case 0:
        Joystick.setXAxis(map(analog_value[0], 0, 1023, -127, 127));                            // Sets this joystick axis to variable and rescales it using a map (value, min input, max input, min output, max output)
      break;
      case 1:
        Joystick.setYAxis(map(analog_value[1], 0, 1023, -127, 127));
      break;
      case 2:
        Joystick.setZAxis(map(analog_value[2], 0, 1023, -127, 127));
      break;
      case 3:
        Joystick.setXAxisRotation(map(analog_value[3], 0, 1023, 0, 359));
      break;
    }
   } //END read analogues

/*
  //Use serial prints for debugging
  
  Serial.print(analog_value[0]);
  Serial.print("\t");
  Serial.print(analog_value[1]);
  Serial.print("\t");
  Serial.print(analog_value[2]);
  Serial.print("\t");
  Serial.println(analog_value[3]);
*/

   
}

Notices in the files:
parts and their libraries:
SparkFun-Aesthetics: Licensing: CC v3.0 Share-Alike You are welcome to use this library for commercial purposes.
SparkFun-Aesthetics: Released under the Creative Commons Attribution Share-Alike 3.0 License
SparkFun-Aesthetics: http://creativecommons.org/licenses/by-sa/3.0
